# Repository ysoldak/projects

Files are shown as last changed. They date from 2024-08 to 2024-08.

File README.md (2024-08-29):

# Yurii's projects and build guides

## Projects
- [Micro Camera Gimbal](https://cults3d.com/en/3d-model/gadget/micro-camera-gimbal-ysoldak)
- [Head Tracker](https://github.com/ysoldak/HeadTracker)

## Build guides
- [FlightLine Fw190 Dora 850mm + FPV Combat](./FL%20Fw190%20Dora%20850mm/README.md)
- [FlightLine P-51D Mustang 850mm + FPV Combat](./FL%20P-51D%20Mustang%20850mm/README.md)

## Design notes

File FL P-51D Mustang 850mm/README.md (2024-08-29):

# FlightLine P-51D Mustang, 850mm

This document walks you through the process of converting very simple 850mm warbird foam frame to FPV Combat ready plane.  
After every step you have a functional model with some new features added.

See also [FlightLine Fw190 Dora, 850mm](../FL%20Fw190%20Dora%20850mm/)

## Step 0: Base

This is bare base model, just add your favourite receiver, battery and go flying LOS.

<table>
  <tr>
    <td width="45%">
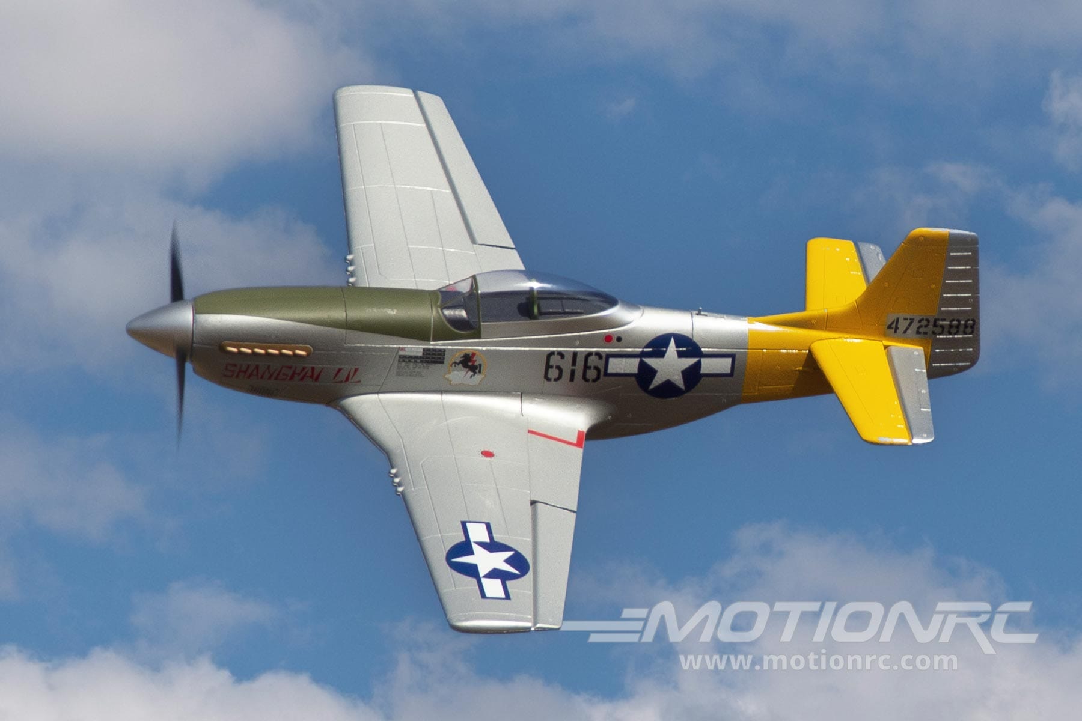
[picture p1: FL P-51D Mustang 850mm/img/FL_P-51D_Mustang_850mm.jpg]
          
    </td>
    <td width="40%">
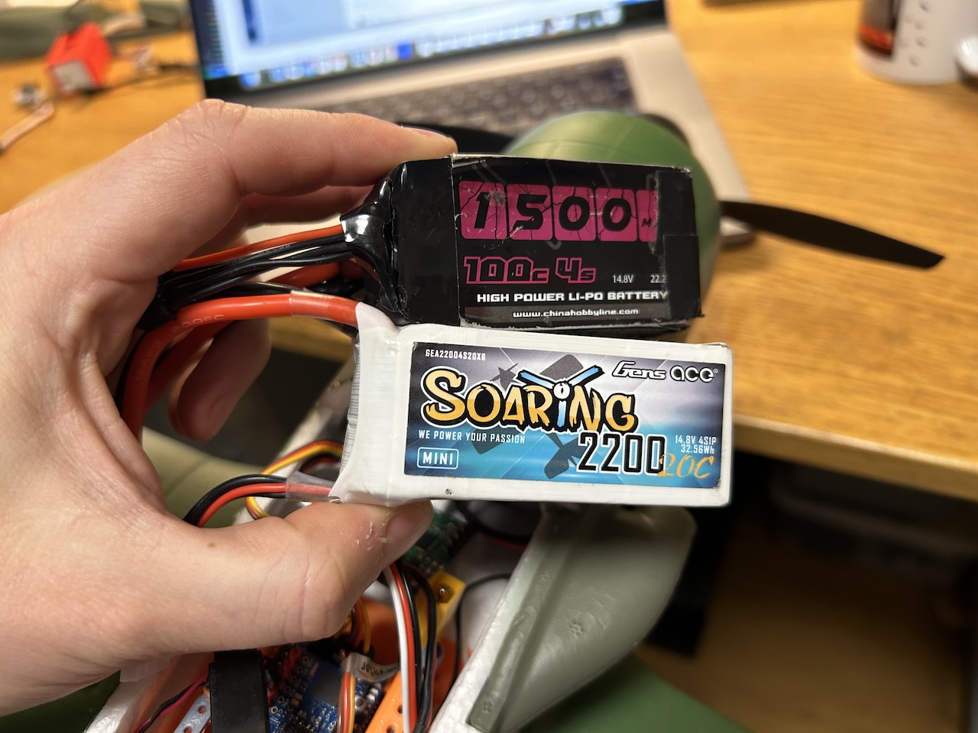
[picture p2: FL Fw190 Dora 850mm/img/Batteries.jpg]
          
    </td>
  </tr>
</table>

### Parts
- Frame (assembled with servos, esc and motor): [FlightLine P-51D Mustang, 850mm](https://www.motionrc.eu/products/flightline-p-51d-mustang-850mm-33-wingspan-pnp-flw101p);
- Receiver: compatible with your system, I use [FrSky Archer Plus R6](https://www.elefun.se/p/prod.aspx?v=59956);
- Battery: Any cheap 1500-2200mAh 4S drone battery.

### Assembly

No special instructions needed here.

### Use

Fly LOS, enjoy the model!

## Step 1: Use Drone motor and Flight Controller (optional)

This step is optional, but recommended.  
**Flight controller** is good to have for convenience features like **auto-launch**.  
**Drone motor** survives crashes and bad landings much better than stock motor which often ends up with a **bent shaft**.

### Parts
- Motor: Any drone motor for 6s (1300-1700kv), for example [Emax ECO II Series 2807](https://droneit.se/product/emax-eco-ii-series-2807-3-6s/)
- Propeller: Any 7-8inch 3-blade 4-6 pitch drone propeller, for example: [Gemfan Cinelifter 8040-3](https://droneit.se/product/gemfan-cinelifter-8040-3-for-cinelifter-freestyle/)
- Spinner: 3D printed in black PLA, see `stl` folder.
- ESC: Either re-use stock ESC or replace it with some 35-45A drone ESC (compact), for example [Aikon AK32 35A 2-6S](https://www.elefun.se/p/prod.aspx?v=40585)
- Flight Controller
  - [Matek F411-WTE](https://www.mateksys.com/?portfolio=f411-wte) ( [Buy](https://www.elefun.se/p/prod.aspx?v=56505) )
  - [SpeedyBee F405 WING MINI](https://www.speedybee.com/speedybee-f405-wing-mini-fixed-wing-flight-controller/) ( [Buy1](https://droneit.se/product/speedybee-f405-wing-mini-easy-fly-fixed-wing-flight-controller/), [Buy2](https://www.elefun.se/p/prod.aspx?v=63418) )
- Base: 3D printed base to mount electronics to, see `stl` folder;
- FC mount: 3D printed FC mount, see "Rail System" project's `stl` folder;

### Assembly

1. Prepare all necessary 3D printed parts;  
   _All parts can be printed without supports!_
2. Remove stock motor, replace with a drone motor, connected to ESC of choice;
3. Spinner and propeller
   1. Install propeller on motor;
   2. Put spinner's lower part on prop;
   3. Tighten with a regular plane prop nut (use a screwdriver or some other metal rod to tighten properly), _not a drone nut with plastic insert -- will not work_!
   4. Place upper spinner part on lower spinner part, and tighten.
4. Remove plywood braket inside the fuselage, we do not need it;
5. Solder servo pins and ESC and battery connectors to the flight controller;
6. Install flight controller on 3D printed base with help of 3D printed brackets;
7. Put the base with FC into fuselage;
8. Connect ESC, servos and receiver;
9. Flash INAV to FC and configure it (see `inav` folder for configuration dumps)  
   _Use DSHOT protocol only with drone ESC!_  
   _Re-calibrate accelerometer for your flight controller!_

### Use

- Arm and throw the model, autolaunch shall engage and keep your model in the air until you move right stick.

## Step 2: Add FPV camera with Head tracking

Enhance your experience, feel like you sit in the cockpit!  

<table>
  <tr>
    <td width="15%">
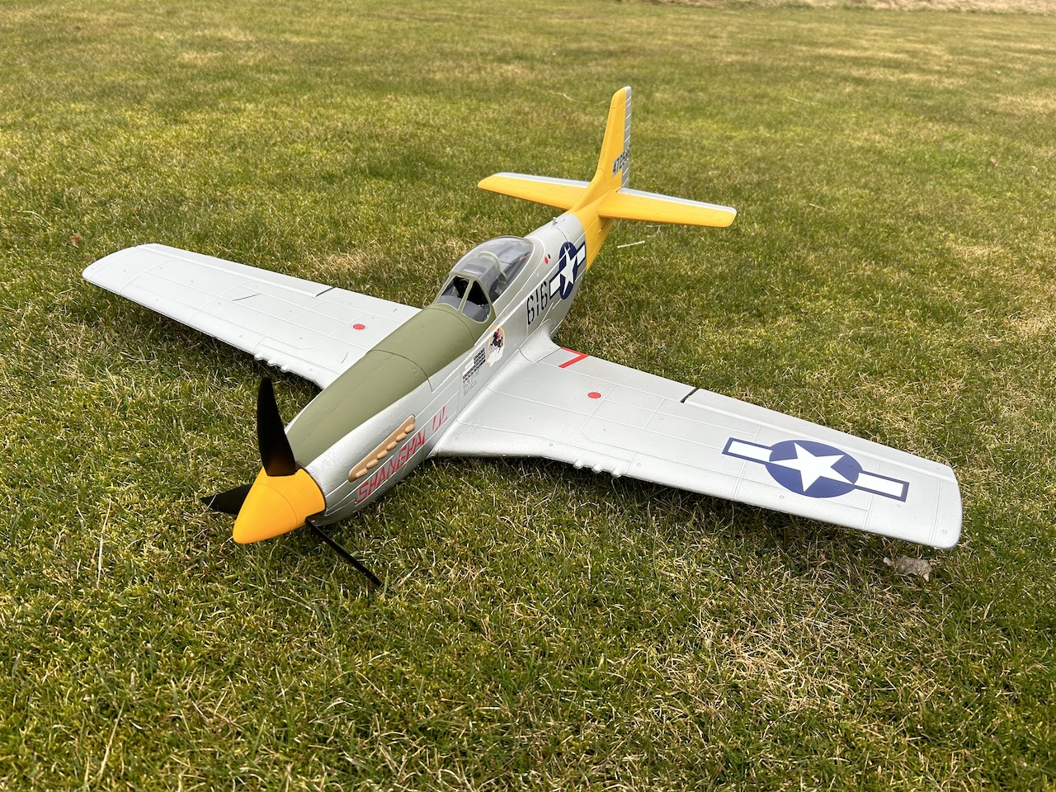
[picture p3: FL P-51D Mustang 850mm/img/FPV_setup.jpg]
      
    </td>
    <td width="15%">
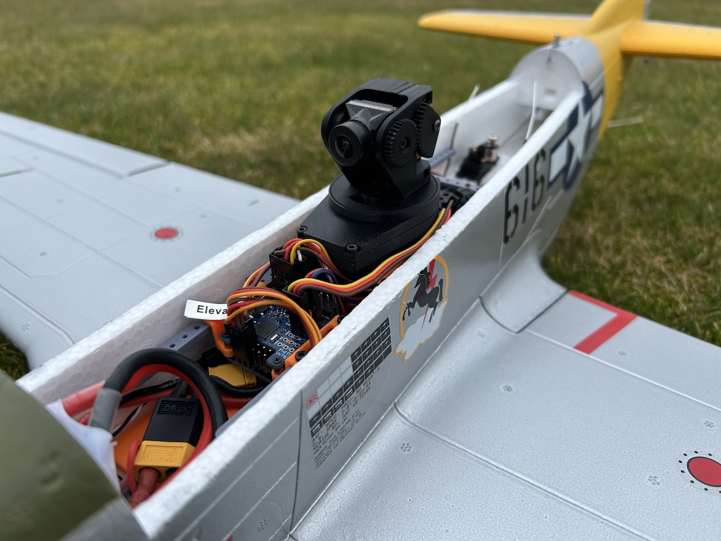
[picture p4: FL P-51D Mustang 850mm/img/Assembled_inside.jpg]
      
    </td>
    <td width="15%">
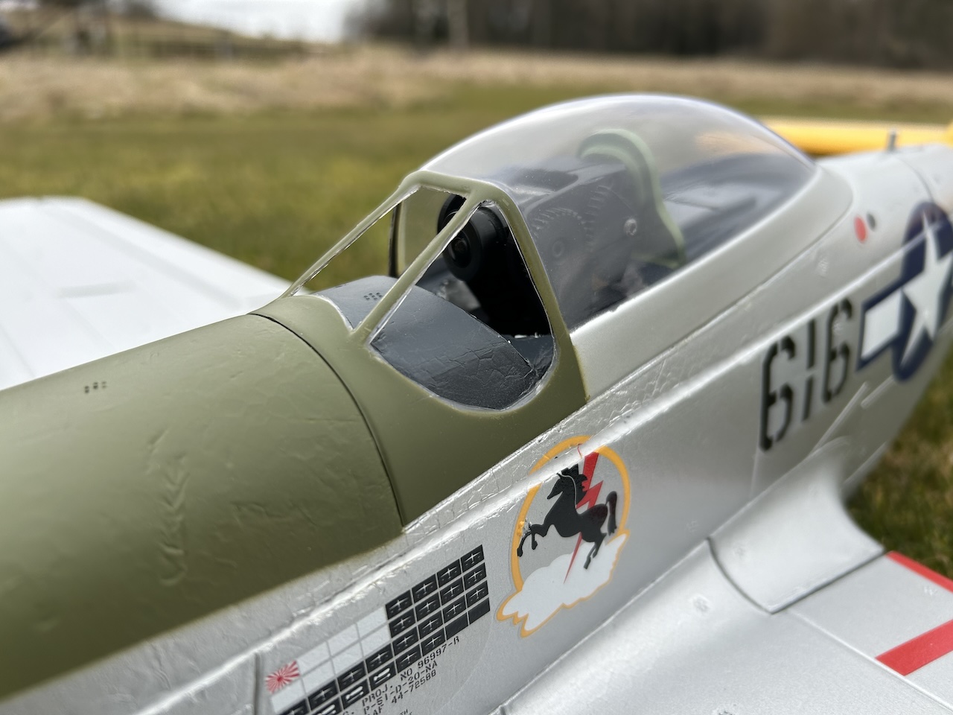
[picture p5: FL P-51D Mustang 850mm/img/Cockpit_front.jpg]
      
    </td>
    <td width="15%">
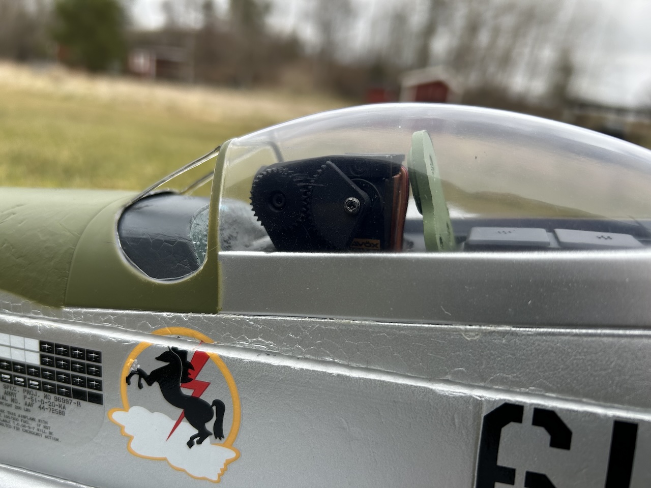
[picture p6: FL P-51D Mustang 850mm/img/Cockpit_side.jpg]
      
    </td>
  </tr>
</table>

### Parts
- Digital video system: one of DJI, Walksnail or HDZero;  
  _I use [Vista](https://www.elefun.se/p/prod.aspx?v=62406) air unit for the rest of this build guide_
- Camera gimbal: 3D printed and assembled [Micro Camera Gimbal](https://cults3d.com/en/3d-model/gadget/micro-camera-gimbal-ysoldak) ( [Buy](https://www.etsy.com/se-en/listing/1572644964/fpv-camera-gimbal-for-micro-servos) );  
  _you'll need two high performance micro servos, such as Savöx SH-0350, TowerPro MG90S or Emax ES08MDII_
- [Head tracking](https://github.com/ysoldak/HeadTracker) system;  
  _or just use your radio's potentiometers_
- Standoffs for camera gimbal: 3D printed, 22mm;  
- Standoffs for air unit: 3D printed, 8mm;
- Cooler fan for air unit: 5v 30x30 cooler fan to prevent air unit overheating inside fuselage;
- Cooler fan mount and antenna holder: 3D printed;
- M2 bolts varous length.

### Assembly

1. Prepare camera gimbal, connect camera to the air unit;
2. Use four M2x18 and four M2x6 bolts to secure air unit to the base;  
   _8mm standoffs go under and fan mount above the air unit_
3. Attach 5v cooler fan on top of air unit;  
   _tip: air unit antenna can go between air unit and the fan_
4. Attach camera gimbal to the base on 22mm standoffs;
5. Connect gimbal servos to flight controller;
6. Connect air unit's MSP cable to flight controller (RX, TX and GND pins);
7. Power air unit from flight controller VBAT pins;
8. Power cooler fan with 5v sourced from either receiver or flight controller;
9. Cut out transparent plastic from cockpit, leaving frame intact;
10. Carve foam from cockpit to fit camera gimbal and to clear wires comming from the flight controller.

## Step 3: Add FPV Combat system

Time to add FPV Combat system.

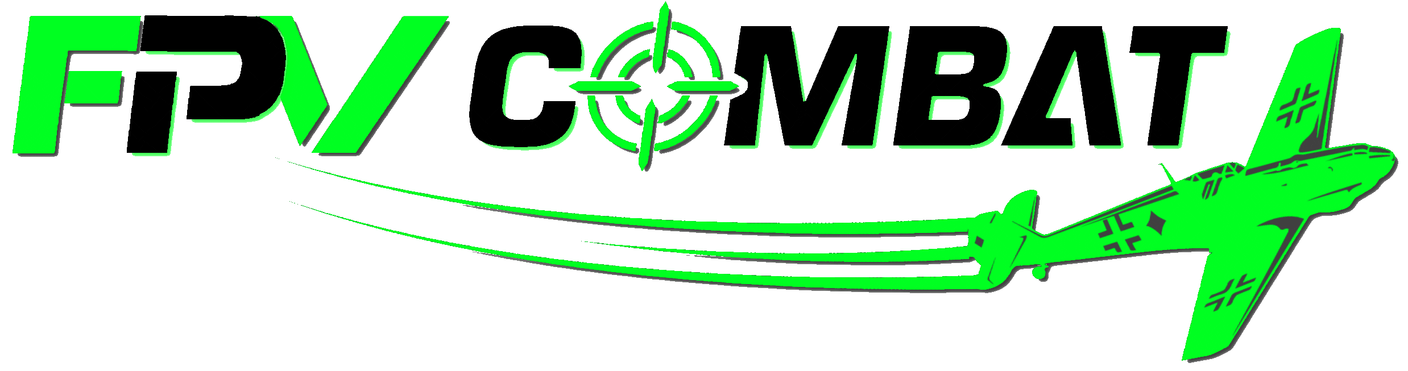
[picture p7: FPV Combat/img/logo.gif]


<table>
  <tr>
    <td width="15%">
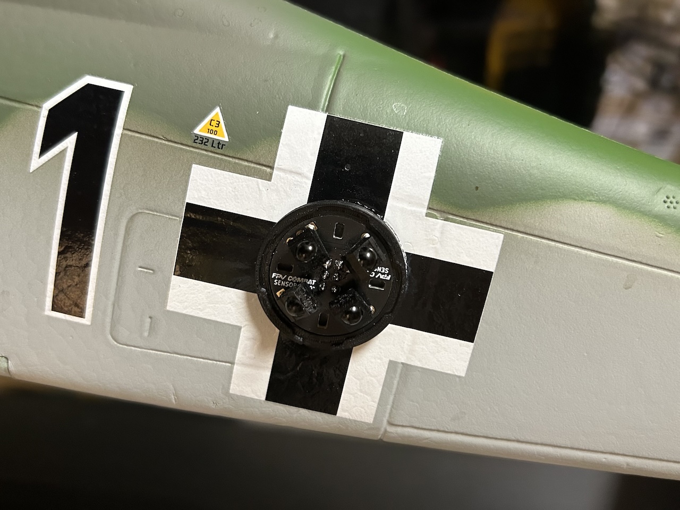
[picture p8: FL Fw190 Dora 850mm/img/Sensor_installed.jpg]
      
    </td>
    <td width="15%">
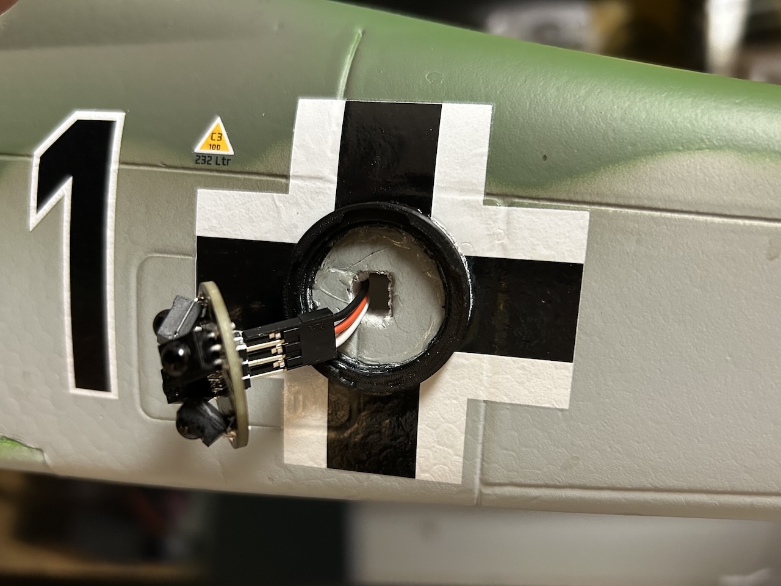
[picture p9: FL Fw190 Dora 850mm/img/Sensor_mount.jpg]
      
    </td>
    <td width="15%">
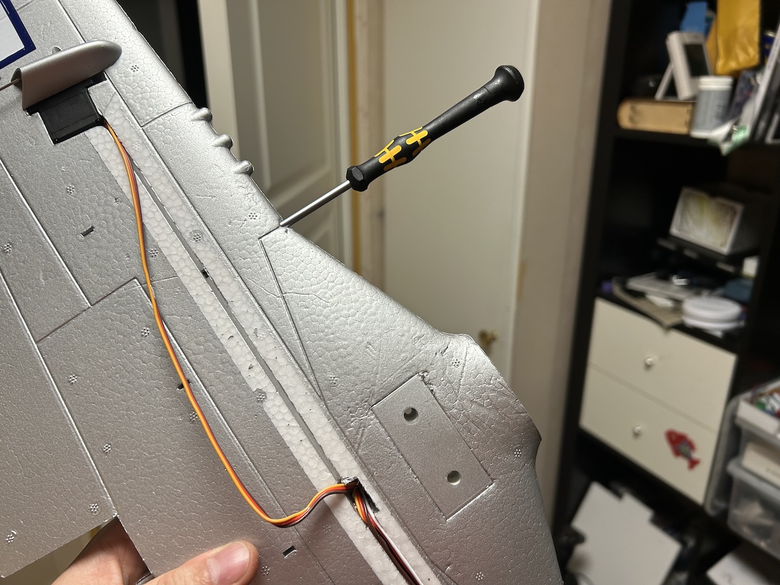
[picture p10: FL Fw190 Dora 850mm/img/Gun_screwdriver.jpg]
      
    </td>
    <td width="15%">
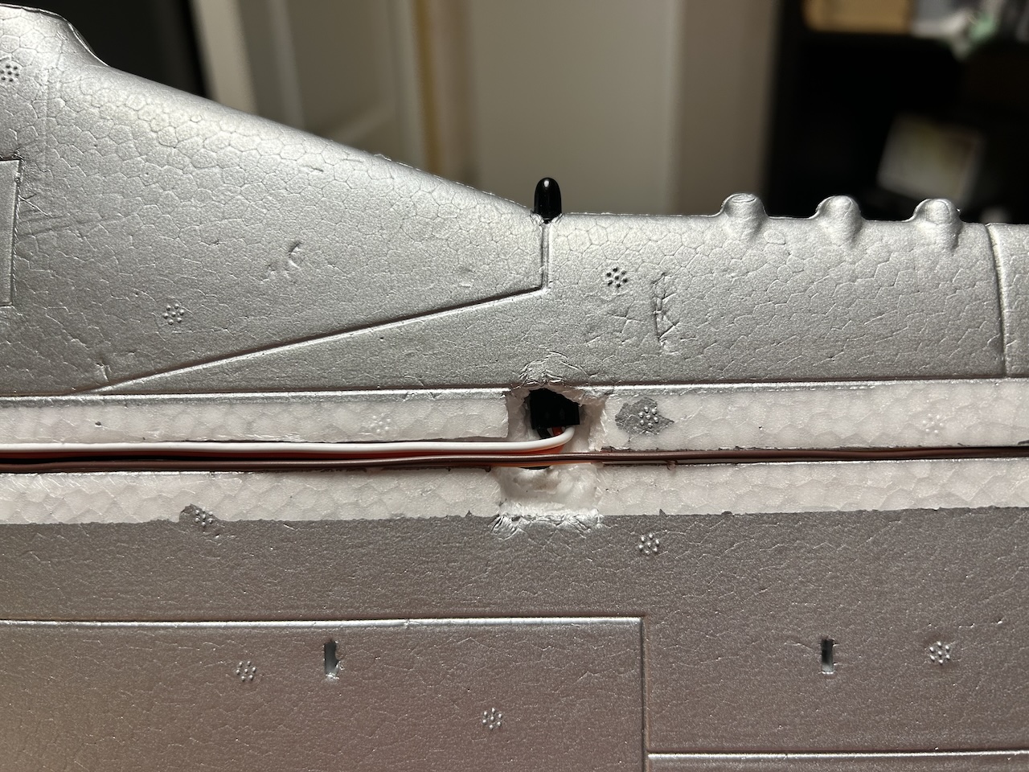
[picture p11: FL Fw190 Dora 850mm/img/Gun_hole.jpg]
      
    </td>
  </tr>
</table>

### Parts
- [FPV Combat board](https://fpv-combat.com/);
- Infrared guns: 2 pieces;
- Infrared sensors: 2 pieces;
- HC-12 board;
- Combat board mount: 3D printed, see "Rail System" project's `stl` folder;
- Sensor holders (optional): 3D printed, see "FPV Combat" project's `stl` folder;

### Assembly
1. Secure combat board to the base via 3D printed mounts, the board shall be centered;
2. Glue sensor holders to each side of fuselage, roughly between wings and tail;  
  _alternatively you can always glue sensors to fuselage directly_
3. Cut foam under the sensor holders;
4. With help of included wires, connect sensors to the combat board and secure sensors in place;
5. Make holes in foam of each wing, 4mm diameter, going from leading edge to servo canal;  
  _use a screwdriver, works great_
6. Carefully pick foam from inside the wings, around the holes, making space for infrared guns;
7. Connect guns to servo wires and insert them all way into wings from servo canal's side, so the gun domes sticks out the leading edge of the wings;
8. Connect guns to the combat board;
9. Connect HC-12 board to the combat board;
10. Connect a servo output either from flight controller or directly from receiver to the trigger pin of the combat board;
11. Connect air unit's RX/TX wires to combat board's MSP pins;  
  _it is possible to add flight controller's OSD, this requires moving HC-12 board to I2C pins and connecting FC MSP to combat board's HC-12 pins_  
12. See [wiring diagrams on fpv combat wiki](https://github.com/FPV-Combat/Main_board_v2/wiki/Wiring-diagrams-for-V2.6)
13. Power combat board from flight controller's VBAT or battery directly.

### Use

Please see [FPV Combat web site](https://fpv-combat.com) and [wiki](https://github.com/FPV-Combat/Main_board_v2/wiki) for information how to configure and use the system.

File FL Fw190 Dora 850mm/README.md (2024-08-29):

# FlightLine Fw190 D-9 Dora, 850mm

This document walks you through the process of converting very simple 850mm warbird foam frame to FPV Combat ready plane.  
After every step you have a functional model with some new features added.

## Step 0: Base

This is bare base model, just add your favourite receiver, battery and go flying LOS.

<table>
  <tr>
    <td width="45%">
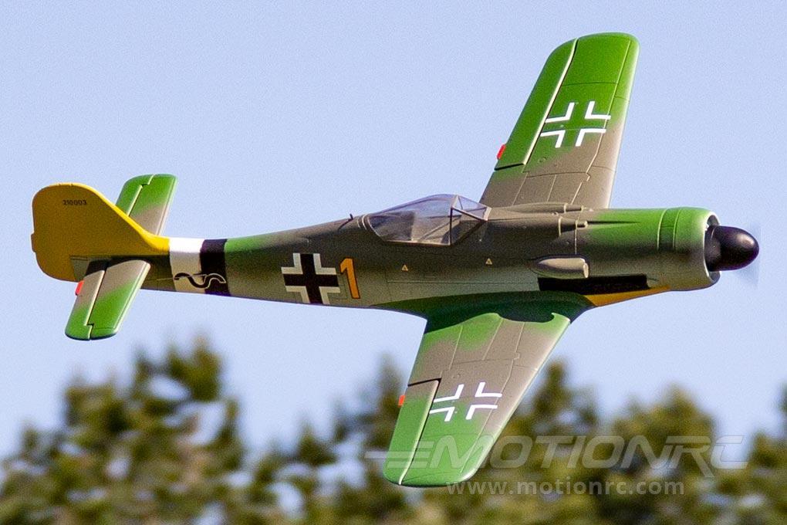
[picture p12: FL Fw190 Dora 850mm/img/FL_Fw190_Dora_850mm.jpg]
          
    </td>
    <td width="40%">
          
    </td>
  </tr>
</table>

### Parts
- Frame (assembled with servos, esc and motor): [FlightLine Fw 190 D-9 Dora, 850mm](https://www.motionrc.eu/products/flightline-fw-190-d-9-dora-850mm-33-wingspan-pnp-flw102p);
- Receiver: compatible with your system, I use [FrSky Archer Plus R6](https://www.elefun.se/p/prod.aspx?v=59956);
- Battery: Any cheap 1500-2200mAh 4S drone battery.

### Assembly

No special instructions needed here.

### Use

Fly LOS, enjoy the model!

## Step 1: Use Drone motor and Flight Controller (optional)

This step is optional, but recommended.  
**Flight controller** is good to have for convenience features like **auto-launch**.  
**Drone motor** survives crashes and bad landings much better than stock motor which often ends up with a **bent shaft**.

<table>
  <tr>
    <td width="15%">
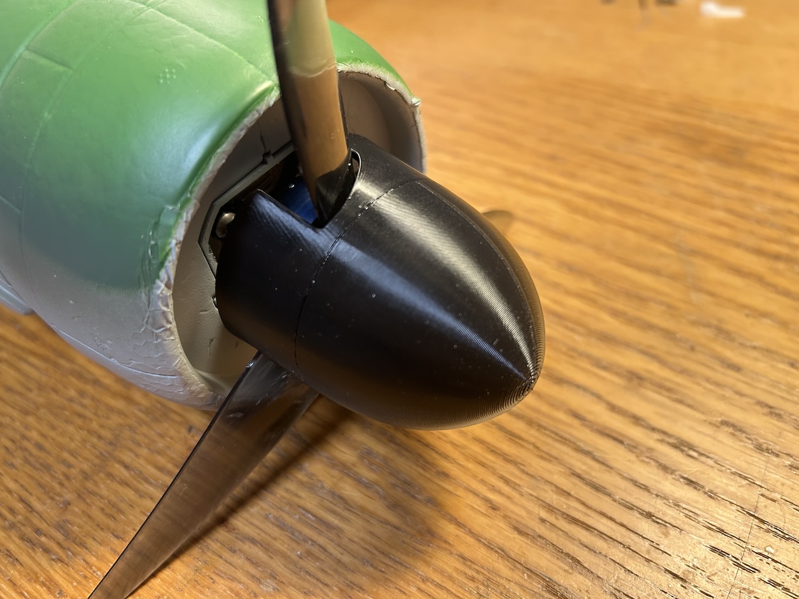
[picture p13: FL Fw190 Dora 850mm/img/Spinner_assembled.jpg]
      
    </td>
    <td width="15%">
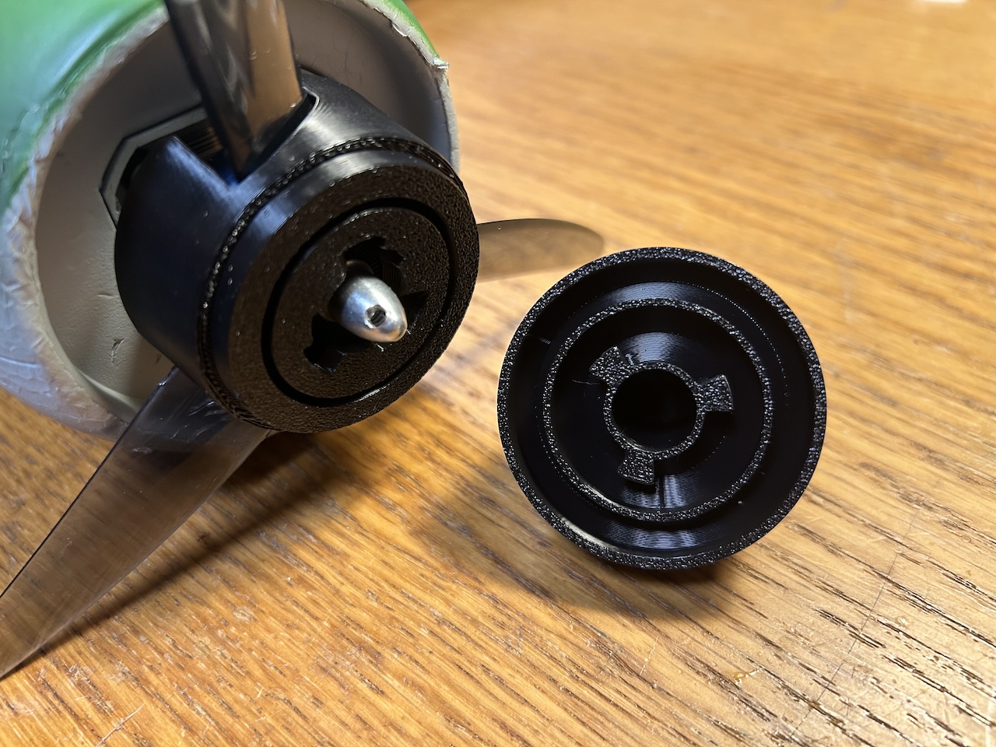
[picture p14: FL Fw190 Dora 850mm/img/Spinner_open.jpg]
      
    </td>
    <td width="15%">
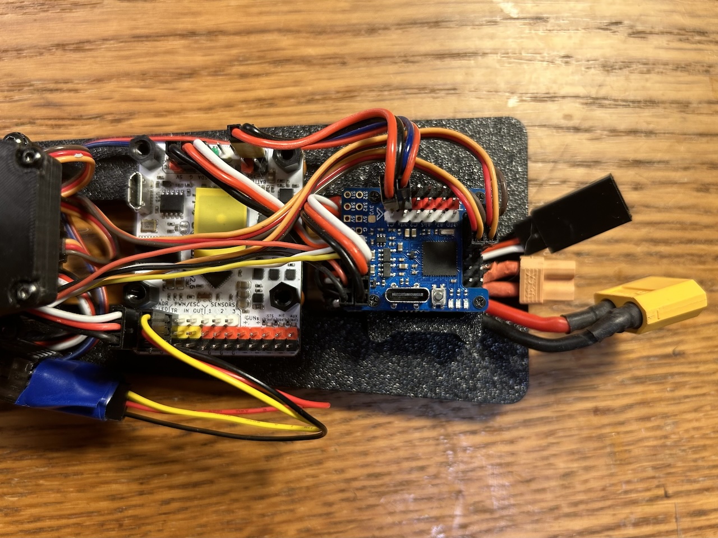
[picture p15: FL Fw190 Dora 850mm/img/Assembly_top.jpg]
      
    </td>
  </tr>
</table>

### Parts
- Motor: Any drone motor for 6s (1300-1700kv), for example [Emax ECO II Series 2807](https://droneit.se/product/emax-eco-ii-series-2807-3-6s/)
- Propeller: Any 7-8inch 3-blade 4-6 pitch drone propeller, for example: [Gemfan Cinelifter 8040-3](https://droneit.se/product/gemfan-cinelifter-8040-3-for-cinelifter-freestyle/)
- Spinner: 3D printed in black PLA, see `stl` folder.
- ESC: Either re-use stock ESC or replace it with some 35-45A drone ESC (compact), for example [Aikon AK32 35A 2-6S](https://www.elefun.se/p/prod.aspx?v=40585)
- Flight Controller
  - [Matek F411-WTE](https://www.mateksys.com/?portfolio=f411-wte) ( [Buy](https://www.elefun.se/p/prod.aspx?v=56505) )
  - [SpeedyBee F405 WING MINI](https://www.speedybee.com/speedybee-f405-wing-mini-fixed-wing-flight-controller/) ( [Buy1](https://droneit.se/product/speedybee-f405-wing-mini-easy-fly-fixed-wing-flight-controller/), [Buy2](https://www.elefun.se/p/prod.aspx?v=63418) )
- Base: 3D printed base to mount electronics to, see `stl` folder;
- FC mount: 3D printed FC mount, see "Rail System" project's `stl` folder;

### Assembly

1. Prepare all necessary 3D printed parts;  
   _All parts can be printed without supports!_
2. Remove stock motor, replace with a drone motor, connected to ESC of choice;
3. Spinner and propeller
   1. Install propeller on motor;
   2. Put spinner's lower part on prop;
   3. Tighten with a regular plane prop nut (use a screwdriver or some other metal rod to tighten properly), _not a drone nut with plastic insert -- will not work_!
   4. Place upper spinner part on lower spinner part, and tighten.
4. Remove plywood braket inside the fuselage, we do not need it;
5. Solder servo pins and ESC and battery connectors to the flight controller;
6. Install flight controller on 3D printed base with help of 3D printed brackets;
7. Put the base with FC into fuselage;
8. Connect ESC, servos and receiver;
9. Flash INAV to FC and configure it (see `inav` folder for configuration dumps)  
   _Use DSHOT protocol only with drone ESC!_  
   _Re-calibrate accelerometer for your flight controller!_

### Use

- Arm and throw the model, autolaunch shall engage and keep your model in the air until you move right stick.

## Step 2: Add FPV camera with Head tracking

Enhance your experience, feel like you sit in the cockpit!  

<table>
  <tr>
    <td width="15%">
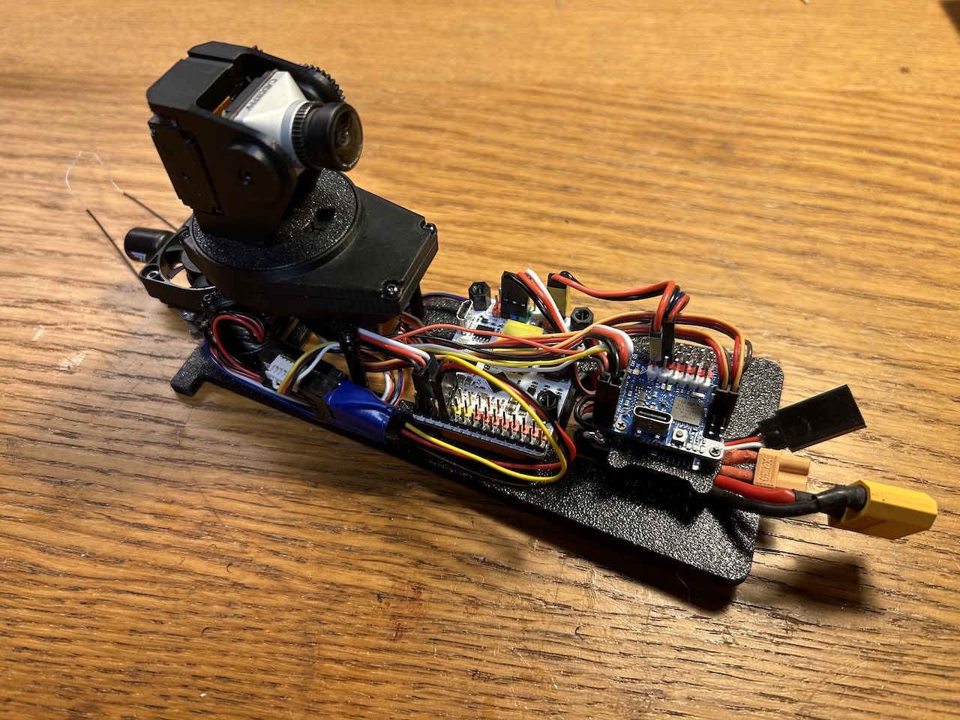
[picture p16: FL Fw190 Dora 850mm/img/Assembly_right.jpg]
      
    </td>
    <td width="15%">
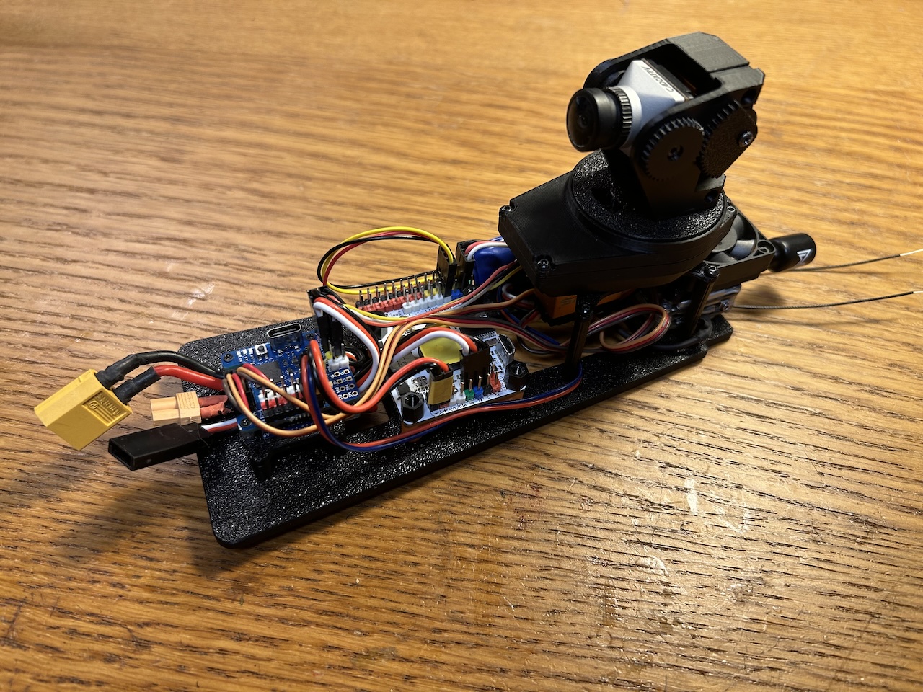
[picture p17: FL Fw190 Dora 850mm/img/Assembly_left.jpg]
      
    </td>
    <td width="15%">
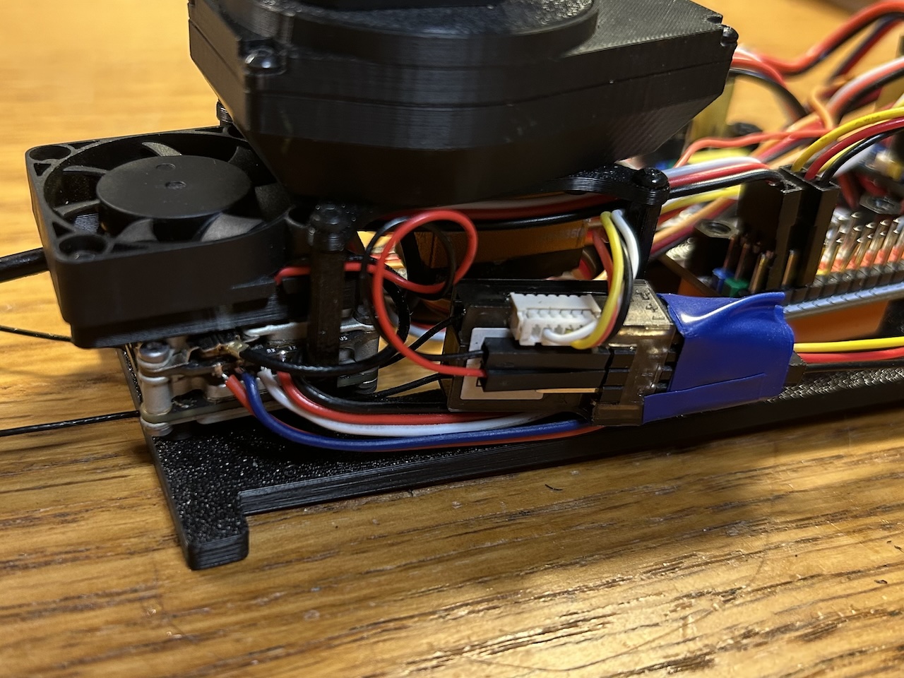
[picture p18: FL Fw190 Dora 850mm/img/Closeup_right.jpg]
      
    </td>
    <td width="15%">
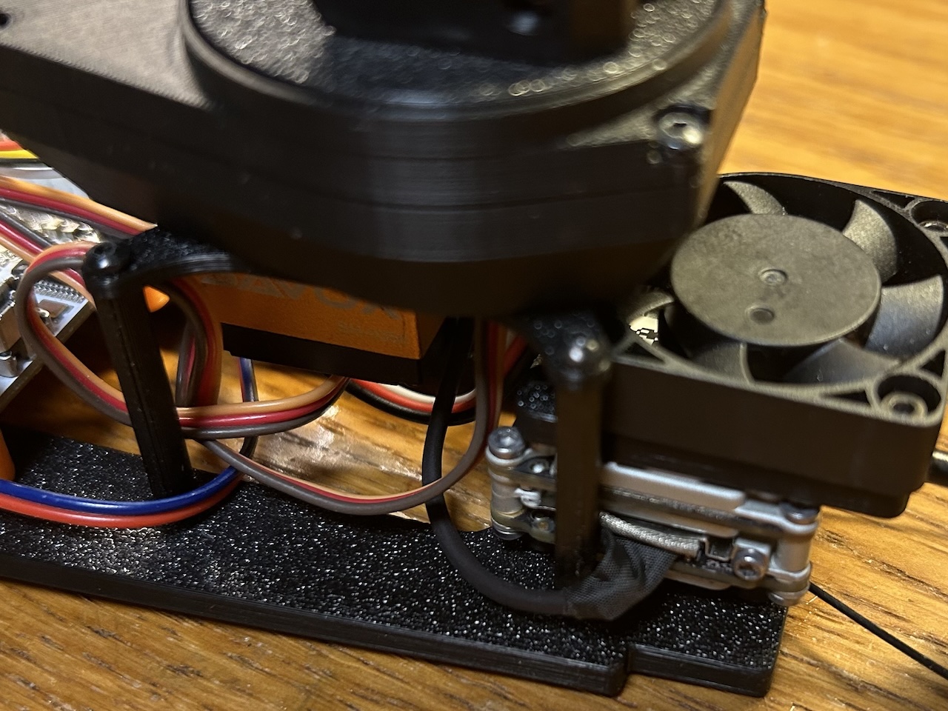
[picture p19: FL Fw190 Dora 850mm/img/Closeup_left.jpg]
      
    </td>
  </tr>
  <tr>
    <td width="15%">
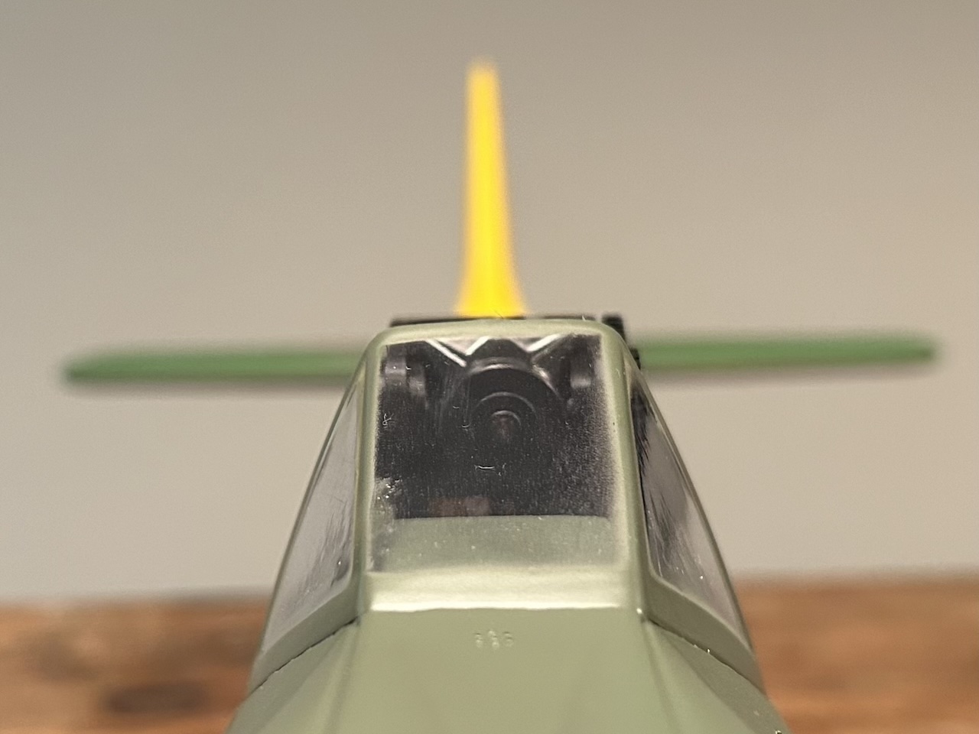
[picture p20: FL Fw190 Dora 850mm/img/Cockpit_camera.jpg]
      
    </td>
    <td width="15%">
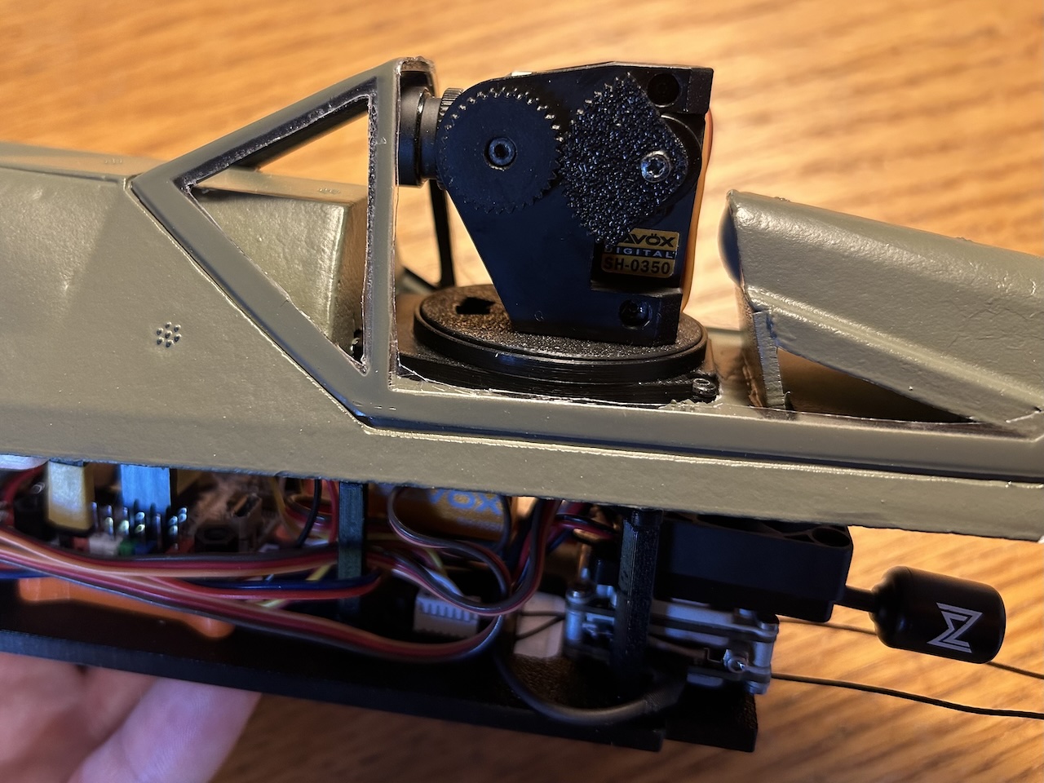
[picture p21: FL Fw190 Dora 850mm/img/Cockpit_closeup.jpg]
      
    </td>
    <td width="15%">
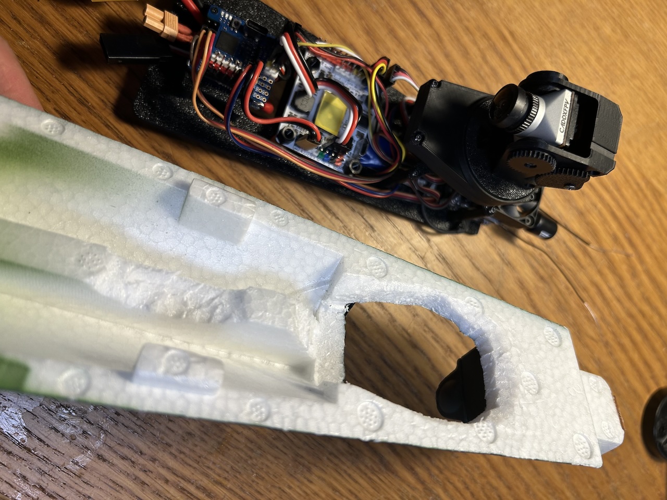
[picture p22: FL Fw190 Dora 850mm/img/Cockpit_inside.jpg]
      
    </td>
    <td width="15%">
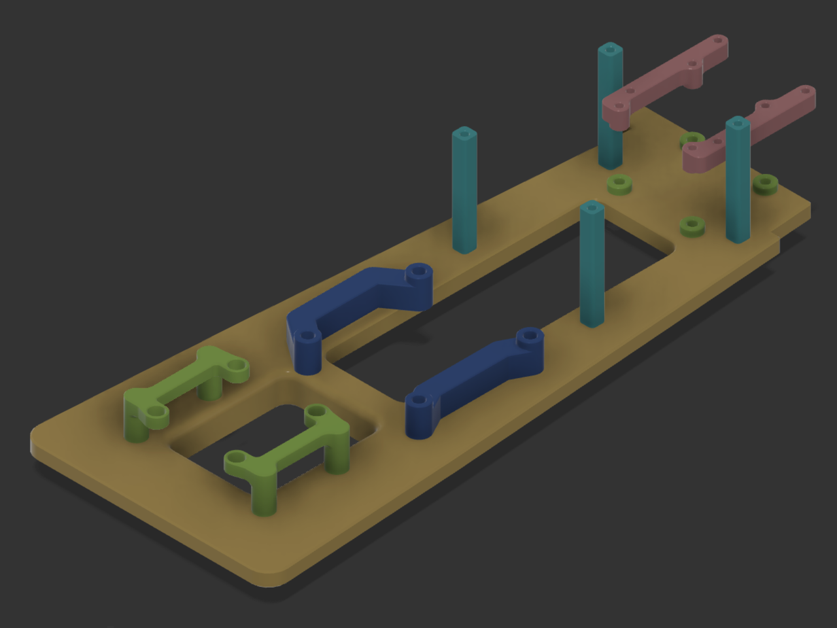
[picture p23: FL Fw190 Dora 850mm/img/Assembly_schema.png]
      
    </td>
  </tr>
</table>

### Parts
- Digital video system: one of DJI, Walksnail or HDZero;  
  _I use [Vista](https://www.elefun.se/p/prod.aspx?v=62406) air unit for the rest of this build guide_
- Camera gimbal: 3D printed and assembled [Micro Camera Gimbal](https://cults3d.com/en/3d-model/gadget/micro-camera-gimbal-ysoldak) ( [Buy](https://www.etsy.com/se-en/listing/1572644964/fpv-camera-gimbal-for-micro-servos) );  
  _you'll need two high performance micro servos, such as Savöx SH-0350, TowerPro MG90S or Emax ES08MDII_
- [Head tracking](https://github.com/ysoldak/HeadTracker) system;  
  _or just use your radio's potentiometers_
- Standoffs for camera gimbal: 3D printed, 27mm;  
  _alternatively, combination of 19mm and 8mm metal standoffs_
-  standoffs for air unit: 3D printed, 2mm;
- Cooler fan for air unit: 5v 30x30 cooler fan to prevent air unit overheating inside fuselage;
- Cooler fan mount: 3D printed;
- Cockpit frame (optional): 3D printed;
- M2 bolts varous length.

### Assembly

1. Prepare camera gimbal, connect camera to the air unit;
2. Use four M2x18 bolts to secure air unit to the base;  
   _2mm standoffs go under and fan mount above the air unit_
3. Attach 5v cooler fan on top of air unit;  
   _tip: air unit antenna can go between air unit and the fan_
4. Attach camera gimbal to the base on 27mm standoffs;
5. Connect gimbal servos to flight controller;
6. Connect air unit's MSP cable to flight controller (RX, TX and GND pins);
7. Power air unit from flight controller VBAT pins;
8. Power cooler fan with 5v sourced from either receiver or flight controller;
9. Cut out transparent plastic from cockpit, leaving frame intact;
10. Optionally, insert 3D printed cockpit into frame to reinforce it;
10. Carve foam from cockpit to fit camera gimbal and to clear wires comming from the flight controller.

## Step 3: Add FPV Combat system

Time to add FPV Combat system.



<table>
  <tr>
    <td width="15%">
      
    </td>
    <td width="15%">
      
    </td>
    <td width="15%">
    </td>
    <td width="15%">
    </td>
  </tr>
  <tr>
    <td width="15%">
      
    </td>
    <td width="15%">
      
    </td>
    <td width="15%">
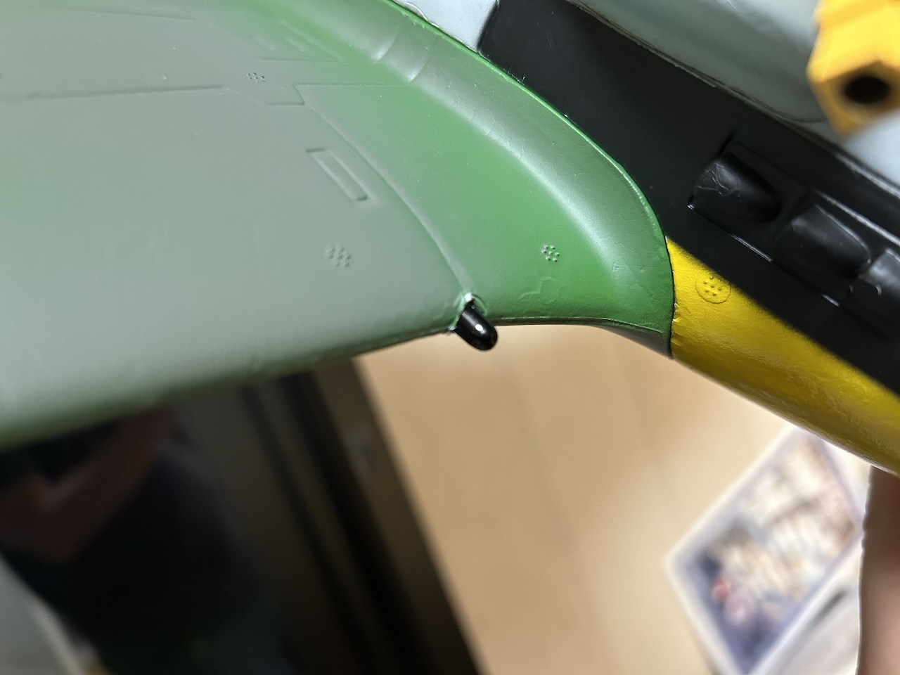
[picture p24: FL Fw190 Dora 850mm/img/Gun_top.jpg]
      
    </td>
    <td width="15%">
      
    </td>
  </tr>
</table>

### Parts
- [FPV Combat board](https://fpv-combat.com/);
- Infrared guns: 2 pieces;
- Infrared sensors: 2 pieces;
- HC-12 board;
- Combat board mount: 3D printed, see "Rail System" project's "stl" folder;
- Sensor holders (optional): 3D printed, see "FPV Combat" project's "stl" folder;

### Assembly
1. Secure combat board to the base via 3D printed mounts, the board shall be centered;
2. Glue sensor holders to each side of fuselage, roughly between wings and tail;  
  _alternatively you can always glue sensors to fuselage directly_
3. Cut foam under the sensor holders;
4. With help of included wires, connect sensors to the combat board and secure sensors in place;
5. Make holes in foam of each wing, 4mm diameter, going from leading edge to servo canal;  
  _use a screwdriver, works great_
6. Carefully pick foam from inside the wings, around the holes, making space for infrared guns;
7. Connect guns to servo wires and insert them all way into wings from servo canal's side, so the gun domes sticks out the leading edge of the wings;
8. Connect guns to the combat board;
9. Connect HC-12 board to the combat board;
10. Connect a servo output either from flight controller or directly from receiver to the trigger pin of the combat board;
11. Connect air unit's RX/TX wires to combat board's MSP pins;  
  _it is possible to add flight controller's OSD, this requires moving HC-12 board to I2C pins and connecting FC MSP to combat board's HC-12 pins_  
12. See [wiring diagrams on fpv combat wiki](https://github.com/FPV-Combat/Main_board_v2/wiki/Wiring-diagrams-for-V2.6)
13. Power combat board from flight controller's VBAT or battery directly.

### Use

Please see [FPV Combat web site](https://fpv-combat.com) and [wiki](https://github.com/FPV-Combat/Main_board_v2/wiki) for information how to configure and use the system.

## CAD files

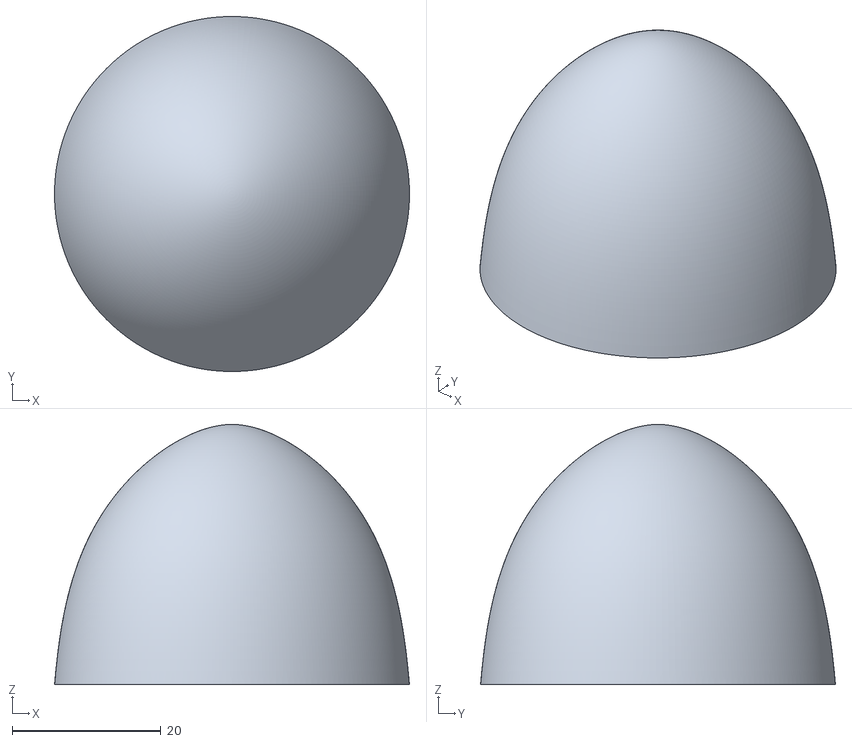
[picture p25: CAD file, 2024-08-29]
FL Fw190 Dora 850mm/stl/FL Fw190 Dora 850mm Spinner Upper.stl
47.8 x 47.8 x 35.0

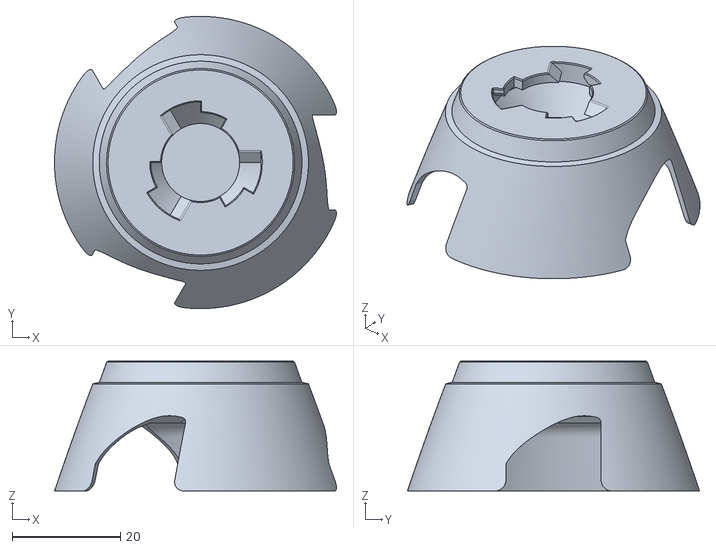
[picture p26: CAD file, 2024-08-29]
FL P-51D Mustang 850mm/stl/FL P-51D Mustang 850mm Spinner Lower.stl
52.1 x 54.0 x 24.0

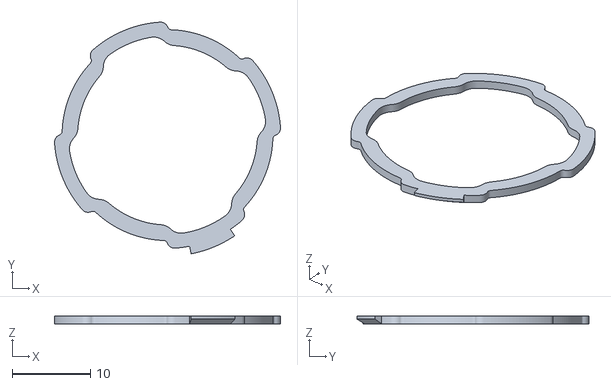
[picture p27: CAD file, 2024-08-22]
FPV Combat/stl/Sensor Lock.stl
28.9 x 29.7 x 1.00

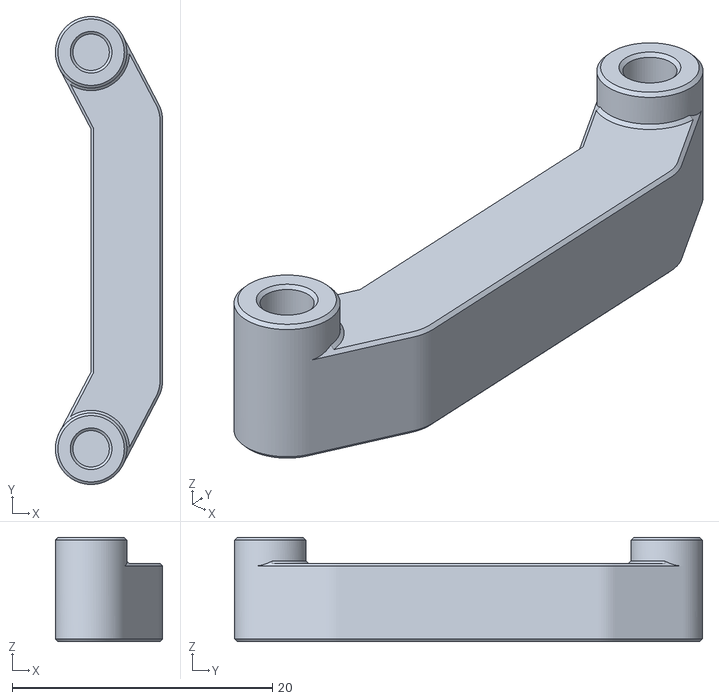
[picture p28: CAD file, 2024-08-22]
Rail System/stl/Bracket FPV Combat Board Part 1.stl
8.25 x 36.0 x 8.00

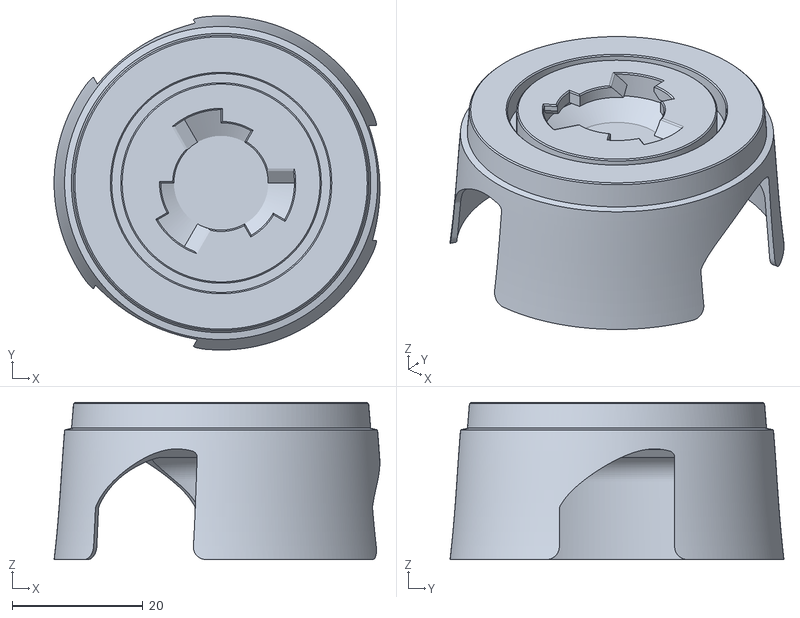
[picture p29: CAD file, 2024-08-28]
FL Fw190 Dora 850mm/stl/FL Fw190 Dora 850mm Spinner Lower.stl
49.7 x 51.0 x 24.0

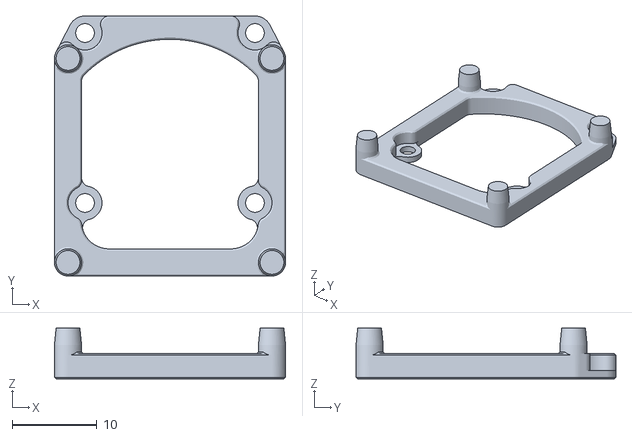
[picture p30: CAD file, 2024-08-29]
FL P-51D Mustang 850mm/stl/FL P-51D Mustang 850mm Vista Fan Holder.stl
27.2 x 30.6 x 6.00

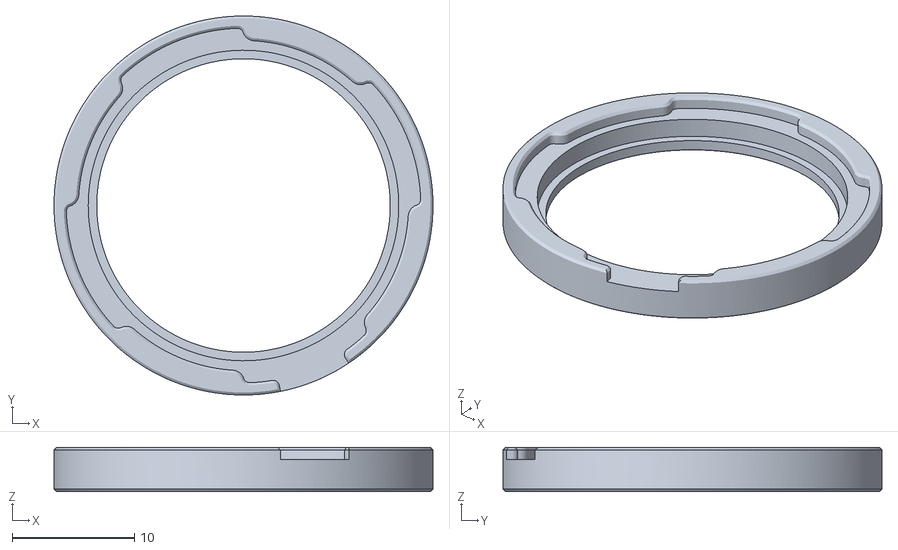
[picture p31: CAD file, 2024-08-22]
FPV Combat/stl/Sensor Base.stl
31.0 x 31.0 x 3.60

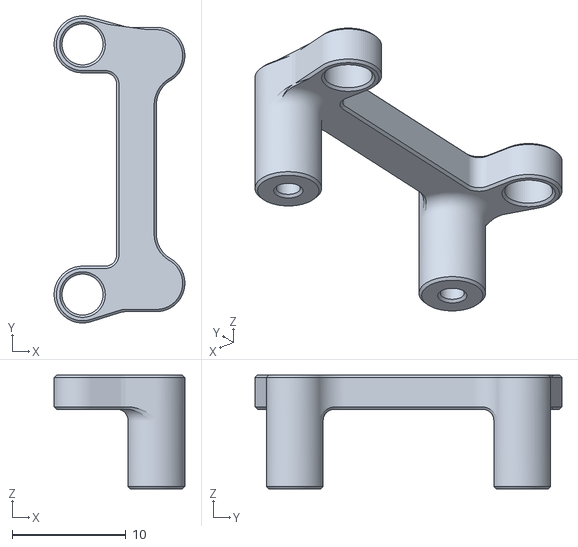
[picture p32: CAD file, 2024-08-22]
Rail System/stl/Bracket Matek F411 3.6mm.stl
11.5 x 27.0 x 10.0

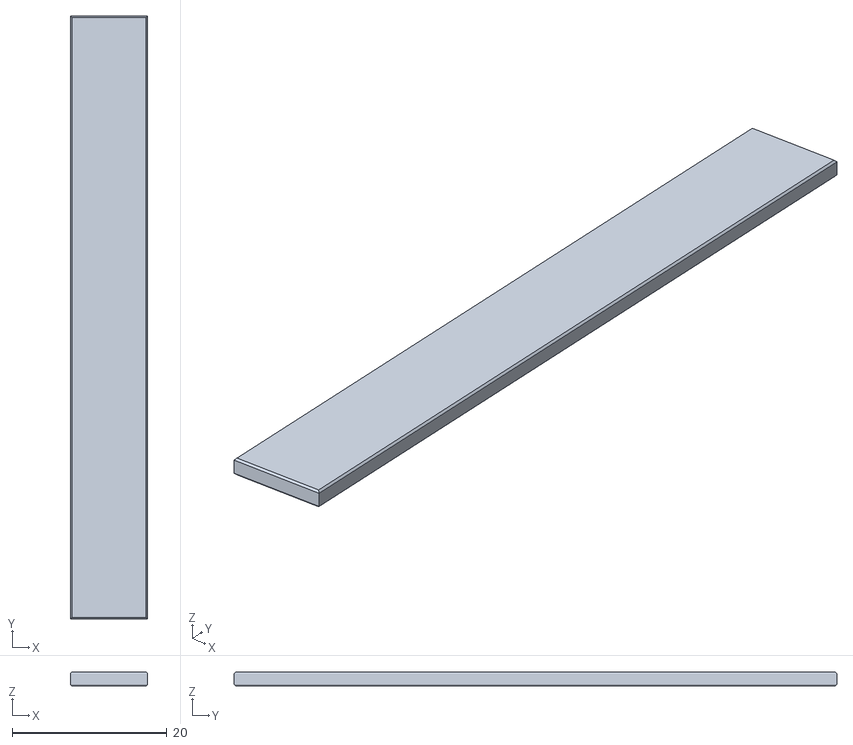
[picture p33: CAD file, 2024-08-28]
FL Fw190 Dora 850mm/stl/FL Fw190 Dora 850mm Battery Shelf.stl
10.0 x 78.0 x 1.80

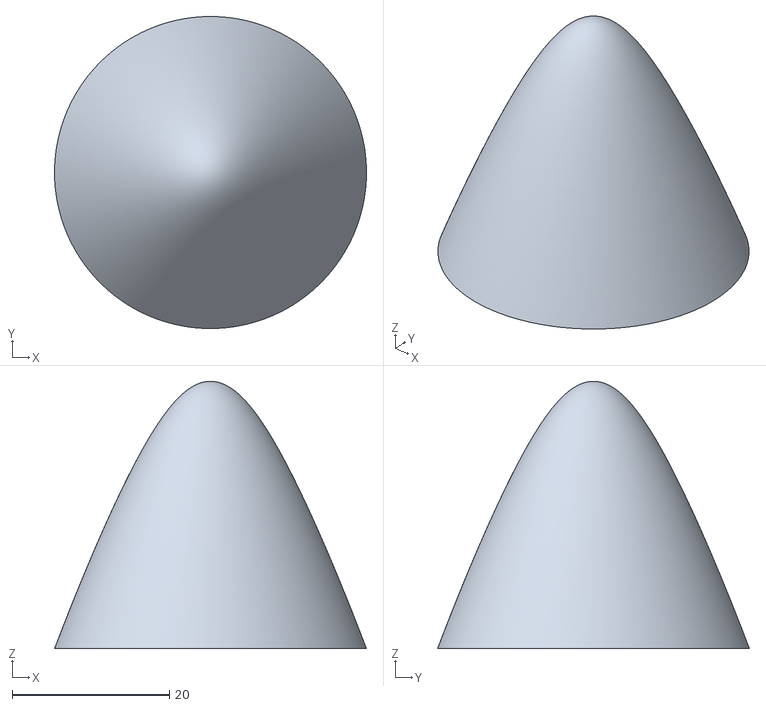
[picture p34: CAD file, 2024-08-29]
FL P-51D Mustang 850mm/stl/FL P-51D Mustang 850mm Spinner Upper.stl
39.7 x 39.7 x 34.0

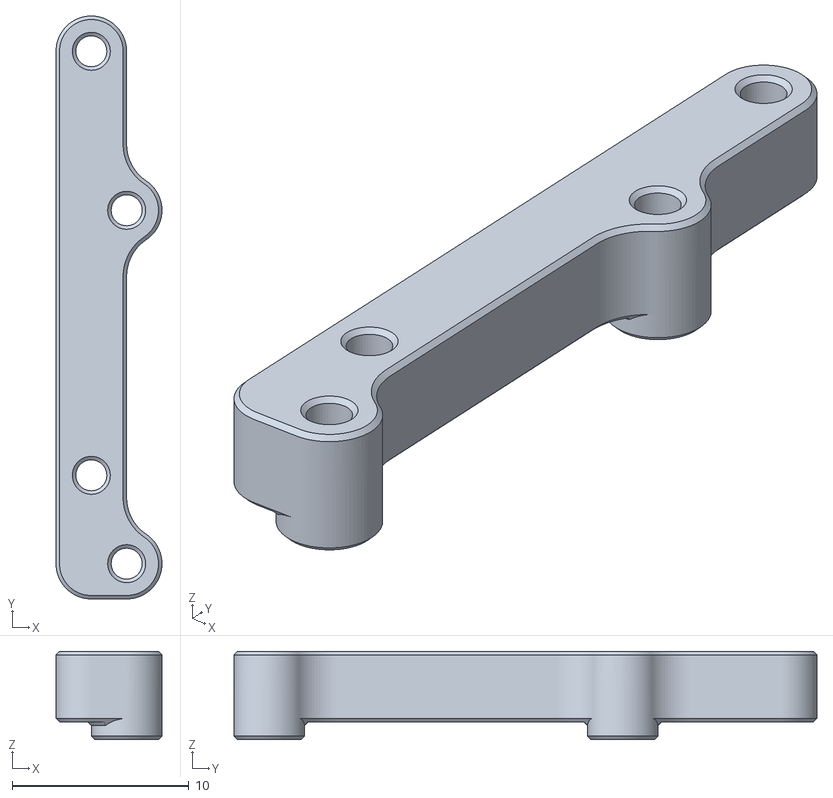
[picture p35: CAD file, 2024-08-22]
FL Fw190 Dora 850mm/stl/FL Fw190 Dora 850mm Vista Fan Holder.stl
6.00 x 33.0 x 5.00

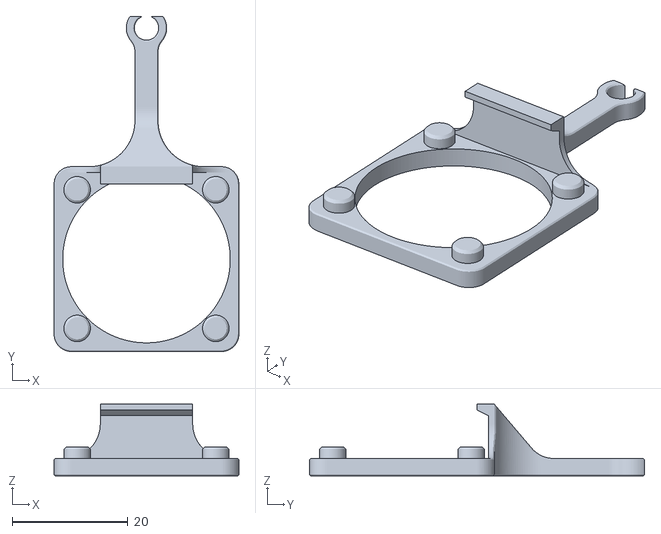
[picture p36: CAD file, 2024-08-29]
FL P-51D Mustang 850mm/stl/FL P-51D Mustang 850mm Antenna Holder.stl
32.0 x 58.0 x 12.4

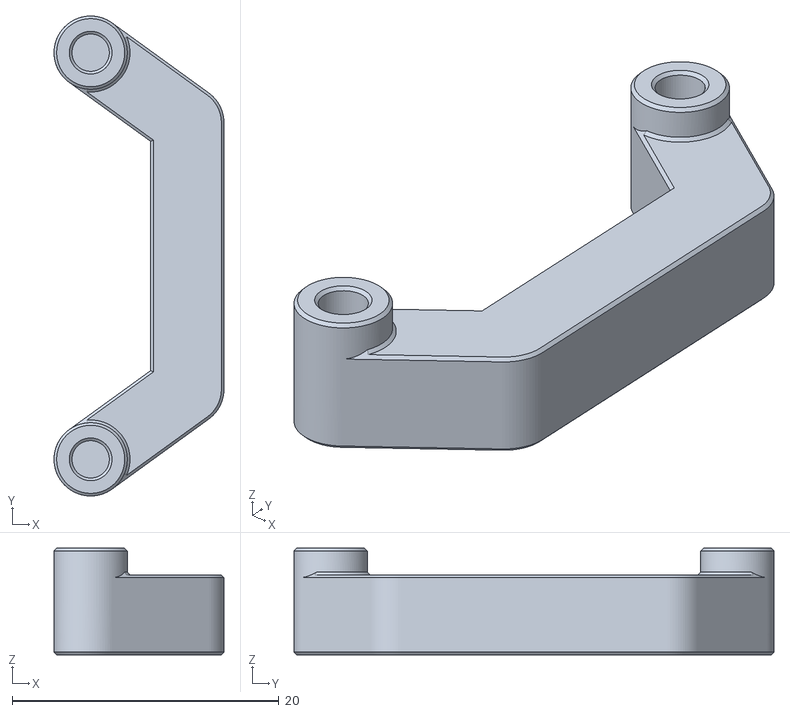
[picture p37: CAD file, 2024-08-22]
Rail System/stl/Bracket FPV Combat Board Part 2.stl
12.8 x 36.0 x 8.00

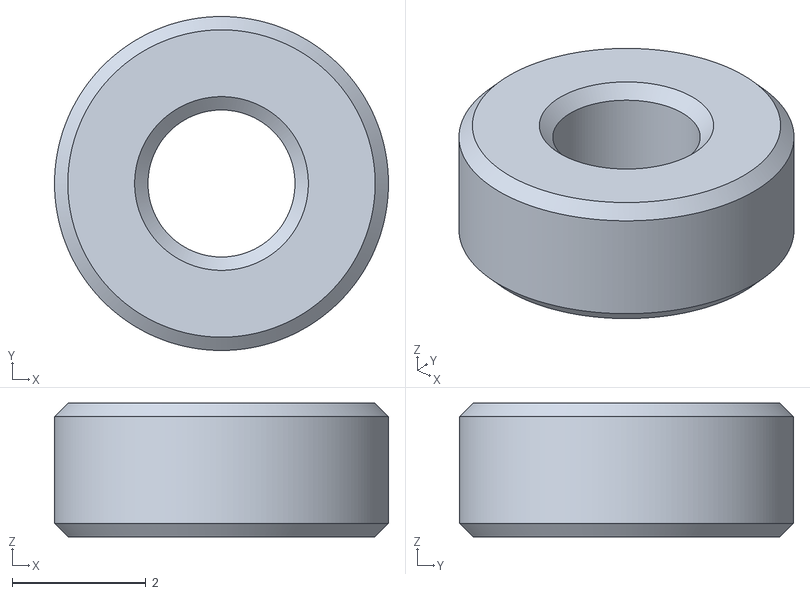
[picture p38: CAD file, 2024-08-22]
FL Fw190 Dora 850mm/stl/FL Fw190 Dora 850mm Vista Standoff 2mm.stl
5.00 x 5.00 x 2.00

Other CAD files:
Rail System/stl/Bracket Matek F411 3.2mm.stl
FL P-51D Mustang 850mm/stl/FL P-51D Mustang 850mm Base.stl
FL Fw190 Dora 850mm/stl/FL Fw190 Dora 850mm Base.stl
FL P-51D Mustang 850mm/stl/FL P-51D Mustang 850mm Standoff 8mm.stl
FL Fw190 Dora 850mm/stl/FL Fw190 Dora 850mm Cockpit Frame.stl
FL Fw190 Dora 850mm/stl/FL Fw190 Dora 850mm Standoff 27mm.stl

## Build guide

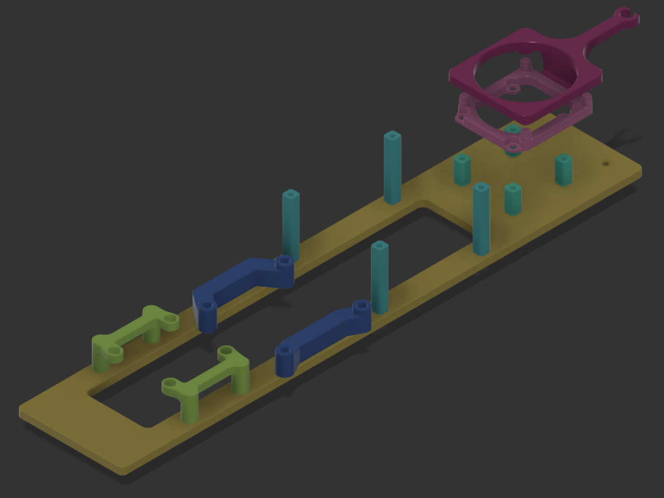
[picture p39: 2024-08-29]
FL P-51D Mustang 850mm/img/Assembly_schema.png

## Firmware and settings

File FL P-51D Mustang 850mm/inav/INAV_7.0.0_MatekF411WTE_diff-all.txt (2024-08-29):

diff all

# version
# INAV/MATEKF411TE 7.0.0 Dec  5 2023 / 10:36:06 (895a4f31)
# GCC-10.3.1 20210824 (release)

# start the command batch
batch start

# reset configuration to default settings
defaults noreboot

# resources

# Timer overrides
timer_output_mode 2 SERVOS
timer_output_mode 3 MOTORS
timer_output_mode 4 SERVOS

# Outputs [servo]
servo 3 1000 2000 1500 50
servo 5 732 2268 1500 100
servo 6 819 2181 1500 100

# safehome

# features
feature -TX_PROF_SEL
feature -SOFTSERIAL
feature THR_VBAT_COMP
feature PWM_OUTPUT_ENABLE
feature FW_LAUNCH

# beeper

# blackbox
blackbox -NAV_ACC
blackbox NAV_POS
blackbox NAV_PID
blackbox MAG
blackbox ACC
blackbox ATTI
blackbox RC_DATA
blackbox RC_COMMAND
blackbox MOTORS
blackbox -GYRO_RAW
blackbox -PEAKS_R
blackbox -PEAKS_P
blackbox -PEAKS_Y

# Receiver: Channel map

# Ports
serial 0 33554432 115200 115200 0 115200

# LEDs

# LED color

# LED mode_color

# Modes [aux]
aux 0 0 0 1800 2100
aux 1 2 1 1400 1600
aux 2 12 1 1800 2100
aux 3 21 3 1800 2100

# Adjustments [adjrange]

# Receiver rxrange

# temp_sensor

# Mission Control Waypoints [wp]
#wp 0 invalid

# OSD [osd_layout]
osd_layout 0 0 42 1 V
osd_layout 0 1 12 0 H
osd_layout 0 7 7 1 V
osd_layout 0 8 24 1 V
osd_layout 0 9 10 19 V
osd_layout 0 11 20 19 V
osd_layout 0 12 1 4 H
osd_layout 0 15 40 9 V
osd_layout 0 16 7 2 H
osd_layout 0 17 7 1 H
osd_layout 0 18 7 3 H
osd_layout 0 25 44 7 H
osd_layout 0 26 42 10 V
osd_layout 0 28 36 19 V
osd_layout 0 30 11 17 V
osd_layout 0 32 28 19 V
osd_layout 0 41 46 11 H
osd_layout 0 42 46 12 H
osd_layout 0 86 37 1 H
osd_layout 1 0 23 0 V
osd_layout 1 1 12 0 V

# Programming: logic

# Programming: global variables

# Programming: PID controllers

# master
set gyro_main_lpf_hz = 25
set dynamic_gyro_notch_q = 250
set dynamic_gyro_notch_min_hz = 30
set gyro_zero_x = 2
set gyro_zero_y = 2
set ins_gravity_cmss =  978.283
set acc_hardware = BMI270
set acczero_x = -2
set acczero_y = -19
set acczero_z = 10
set accgain_x = 4066
set accgain_y = 4058
set accgain_z = 4048
set align_mag = CW270FLIP
set mag_hardware = NONE
set baro_hardware = SPL06
set serialrx_provider = SBUS
set motor_pwm_protocol = DSHOT300
set bat_voltage_src = SAG_COMP
set servo_pwm_rate = 100
set small_angle = 180
set applied_defaults = 3
set airmode_type = STICK_CENTER_ONCE
set nav_wp_radius = 5000
set nav_wp_max_safe_distance = 500
set nav_rth_allow_landing = FS_ONLY
set nav_rth_altitude = 5000
set nav_fw_control_smoothness = 2
set nav_fw_launch_max_angle = 180
set nav_fw_launch_motor_delay = 100
set nav_fw_launch_max_altitude = 5000
set nav_fw_launch_climb_angle = 20
set osd_video_system = BFHDCOMPAT
set osd_left_sidebar_scroll = ALTITUDE
set osd_home_position_arm_screen = OFF
set osd_pan_servo_index = 5
set osd_pan_servo_pwm2centideg = 18
set name = FL P-51D

# mixer_profile
mixer_profile 1

set platform_type = AIRPLANE
set has_flaps = ON
set model_preview_type = 30
set motorstop_on_low = ON

# Mixer: motor mixer

mmix reset

mmix 0  1.000  0.000  0.000  0.000

# Mixer: servo mixer
smix reset

smix 0 4 1 100 0 -1
smix 1 3 0 100 0 -1
smix 2 5 19 100 0 -1
smix 3 6 20 100 0 -1

# profile
profile 1

set fw_p_pitch = 15
set fw_i_pitch = 5
set fw_d_pitch = 5
set fw_ff_pitch = 74
set fw_p_roll = 15
set fw_i_roll = 1
set fw_d_roll = 2
set fw_ff_roll = 33
set fw_p_yaw = 50
set fw_i_yaw = 0
set fw_d_yaw = 20
set fw_ff_yaw = 255
set max_angle_inclination_rll = 450
set dterm_lpf_hz = 10
set fw_turn_assist_pitch_gain =  0.400
set nav_fw_pos_z_p = 25
set nav_fw_pos_z_d = 8
set nav_fw_pos_xy_p = 55
set d_boost_min =  1.000
set d_boost_max =  1.000
set rc_expo = 30
set rc_yaw_expo = 30
set roll_rate = 36
set pitch_rate = 18
set yaw_rate = 3

# profile
profile 2


# profile
profile 3


# battery_profile
battery_profile 1

set battery_capacity = 1500
set battery_capacity_warning = 750
set battery_capacity_critical = 450
set throttle_idle =  5.000
set nav_fw_launch_idle_thr = 1300

# battery_profile
battery_profile 2


# battery_profile
battery_profile 3


# restore original profile selection
mixer_profile 1
profile 1
battery_profile 1

# save configuration
save

# 

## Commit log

2024-08-22 Dora build guide
    [Bracket FPV Combat Board Part 1.stl, Bracket FPV Combat Board Part 2.stl, Bracket Matek F411 3.2mm.stl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]
2024-08-22 inav dump
    [INAV_7.1.2_diff-all_20240823.txt]
2024-08-28 Dora updates
    [FL Fw190 Dora 850mm Battery Shelf.stl, FL Fw190 Dora 850mm Spinner Lower.stl, FL Fw190 Dora 850mm Spinner Upper.stl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]
2024-08-29 Improved Dora spinner upper part for better fit
    [FL Fw190 Dora 850mm Spinner Upper.stl]
2024-08-29 Dora assembly schema
2024-08-29 Fix Dora assembly schema
2024-08-29 Mustang build guide added
    [FL P-51D Mustang 850mm Antenna Holder.stl, FL P-51D Mustang 850mm Base.stl, FL P-51D Mustang 850mm Spinner Lower.stl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]
